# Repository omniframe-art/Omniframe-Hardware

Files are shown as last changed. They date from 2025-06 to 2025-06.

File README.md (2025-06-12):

**Omniframe Hardware**

Omniframe is an open source e-paper digital frame. This repository includes the source and fabrication files for the main and secondary boards for driving the [13.3" Monochrome e-ink display](https://www.eink.com/product/detail/VB3300-NCB).

Screenshot 2025-06-12 at 5 02 29 PM

Main Board includes:
* ESP32-S3 N8R2
* TPS65185
* AP61100
* BQ25505
* BQ24040
* MicroSD card slot
  
Screenshot 2025-06-10 at 2 24 29 PM

Secondary Board includes:
* USB Type-C Port
* Pushbutton connected to ESP GPIO

Exports include:
* Gerber files
* Assembly files
* BOM
* STEP files

The main board includes Molex 5023520-series connectors for Solar Array, Battery, and and Secondary Board. By default, connecting the main and secondary boards is done with a ribbon cable with [Molex 5023510500](https://www.digikey.com/en/products/detail/molex/5023510500/4555379) housings. Alternatively, the source files can be modified to accomodate for other connectors. 

To operate the e-paper display using this hardware, flash the [Omniframe Firmware](https://github.com/omniframe-art/Omniframe-Firmware) to the ESP. For converting and transferring images set up the [Private Image Server](https://github.com/omniframe-art/Private-Image-Server).

**Licensing**

The Omniframe framework is licensed under the terms of the [Creative Commons Attribution-ShareAlike 4.0 International License](https://creativecommons.org/licenses/by-sa/4.0/).

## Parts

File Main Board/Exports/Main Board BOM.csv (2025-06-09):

Reference | Value | Footprint | Qty | DNP | Description
C1,C46 | 2u2 | Capacitor_SMD:C_0805_2012Metric | 2 |  | Capacitor
C2,C4,C22,C31,C47,C48 | 100n | Capacitor_SMD:C_0603_1608Metric | 6
C3,C23,C32,C36,C42 | 22u | Capacitor_SMD:C_0805_2012Metric | 5
C5,C13,C26,C27,C28,C33,C34,C45,C51,C52,C53 | 4u7 | Capacitor_SMD:C_0805_2012Metric | 11
C9,C10,C11,C49 | 10n | Capacitor_SMD:C_0603_1608Metric | 4
C20,C21 | 1u | Capacitor_SMD:C_0805_2012Metric | 2
C30,C35,C43,C50,C59 | 10u | Capacitor_SMD:C_0805_2012Metric | 5
C54,C55,C58 | 1uF/25V | Capacitor_SMD:C_0805_2012Metric | 3
C56,C57 | 1uF/50V | Capacitor_SMD:C_0805_2012Metric | 2
D1,D9 | BAS3010B-03W | Diode_SMD:D_SOD-323 | 2
D7,D8 | BAV99,215 | Libraries:SOT-23TO-236_318-08_ONS-M | 2
H1,H2,H3,H4 | MountingHole | MountingHole:MountingHole_3.2mm_M3 | 4
IC1 | ESP32-S3-WROOM-1-N8R2 | ESP:ESP32S3WROOM1N8R2 | 1 |  | WiFi Modules - 802.11 (Engineering Samples Only) SMD Module, ESP32-S3R2, 2 MB PSRAM, 8 MB SPI Flash, PCB Antenna ,,
IC2 | TPS65185RSLT | TPS65185:QFN40P600X600X100-49N-D | 1 |  | Power Management Specialised - PMIC PMIC FOR E-INK PAPER DISPLAY
IC4 | AP61100 | AP61300:SOTFL50P162X60-6N | 1 |  | DCDC Conv LV Buck SOT563 T&R 3K
J2 | 5023520300 | 5023520300:CONN03_502352_MOL | 1
J3 | FH26W-39S-0.3SHW(60) | Libraries:FH26W39S03SHW60 | 1
J4 | 5023520500 | 5023520500:CONN05_502352_MOL | 1
J5 | MSD-1-A | MSD-1-A:CUI_MSD-1-A | 1
J6 | 5023520200 | 5023520200:CONN02_502352_MOL | 1
L1 | 4.7uH 2A | Inductor_SMD:L_Vishay_IFSC-1515AH_4x4x1.8mm | 1
L3 | LPS4018-223MRC | LPS4018_223MRC:IND_LPS4018-223MRC | 1
L4 | NRH3012T1R0NN | Inductor_SMD:L_Changjiang_FNR3012S | 1
L5 | 2.2uH 2A | Inductor_SMD:L_Changjiang_FNR4012S | 1 |  | Inductor
Q1,Q5 | 2N7002 | Libraries:SOT-23TO-236_318-08_ONS-M | 2 |  | N-MOSFET transistor, drain/source/gate
Q2,Q4,Q6 | BSS84-7-F | Package_TO_SOT_SMD:SOT-23-3 | 3 |  | P-MOSFET transistor, drain/source/gate
R1,R5,R8,R15,R16,R17,R18,R30,R33,R34 | 10k | Resistor_SMD:R_0402_1005Metric | 10
R10,R12,R14,R40,R41,R42,R43 | 47k | Resistor_SMD:R_0402_1005Metric | 7
R11,R19 | 30k | Resistor_SMD:R_0402_1005Metric | 2
R13 | 7M32 | Resistor_SMD:R_0402_1005Metric | 1
R20 | 5M62 | Resistor_SMD:R_0402_1005Metric | 1
R21 | 1M1 | Resistor_SMD:R_0402_1005Metric | 1
R22 | 7M68 | Resistor_SMD:R_0402_1005Metric | 1
R23 | 2k | Resistor_SMD:R_0402_1005Metric | 1
R25 | 44k2 | Resistor_SMD:R_0402_1005Metric | 1
R26 | 200k | Resistor_SMD:R_0402_1005Metric | 1
R27 | 4M22 | Resistor_SMD:R_0402_1005Metric | 1
R28 | 590 | Resistor_SMD:R_0402_1005Metric | 1
R35 | 52k3 | Resistor_SMD:R_0402_1005Metric | 1
R36,R38 | 1M | Resistor_SMD:R_0402_1005Metric | 2
R37 | 41k6 | Resistor_SMD:R_0402_1005Metric | 1
R39 | 43k | Resistor_SMD:R_0402_1005Metric | 1
R44 | 100k | Resistor_SMD:R_0402_1005Metric | 1
S1 | TS5216A 160gf 025 | TS18-5-25-SL-260-SMT-TR:TS18525SL260SMTTR | 1 |  | None Without 50mA 5.2mm 100MΩ 100000 Times 12V 160gf 5.2mm 1.6mm Round Button Standing paste SPST SMD-4P,5.2x5.2mm Tactile Switches ROHS
TH1 | 10k/3380K | Resistor_SMD:R_0402_1005Metric | 1
U1 | BQ25505 | bq25505:QFN50P350X350X100-21N-D | 1 |  | Nano Power Boost Charger and Buck Converter for Energy Harvester Powered Applications, QFN-20
U3 | BQ24040DSQR | BQ24040:SON40P200X200X80-11N | 1
Y1 | SIT1533AC-H4-DCC-32.768E | Libraries:XTAL4_SiT1533_SIT | 1

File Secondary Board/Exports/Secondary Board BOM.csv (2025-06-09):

Id | Designator | Footprint | Quantity | Designation | Supplier and ref
1 | J3 | CONN05_502352_MOL | 1 | 5023520500
2 | R2,R1 | R_0402_1005Metric | 2 | 5k1
3 | J1 | USB4145030070C | 1 | USB4145-03-0070-C
4 | S2 | TL1014BF220QG | 1 | TL1014BF220QG
5 | B1 | SOT-23-6 | 1 | USBLC6-2SC6

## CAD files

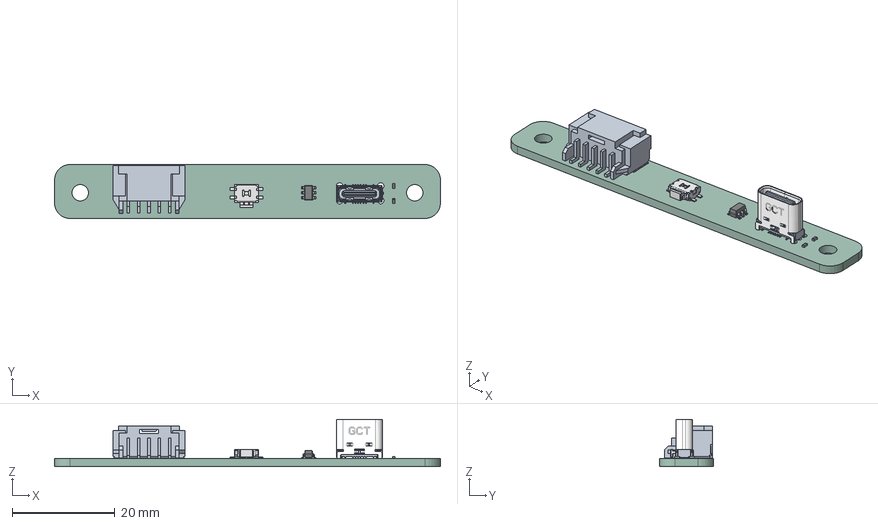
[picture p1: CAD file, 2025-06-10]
Secondary Board/Exports/Secondary Board.step
75.0 x 10.5 x 9.22 mm
R_0402_1005Metric x 2
USB4145-03-0070-C
P:\E-Switch Secure\3D_MODELS_STP_FORMAT\TL1014BFxxxQG.stp
SOT_23_6
Secondary Board_PCB

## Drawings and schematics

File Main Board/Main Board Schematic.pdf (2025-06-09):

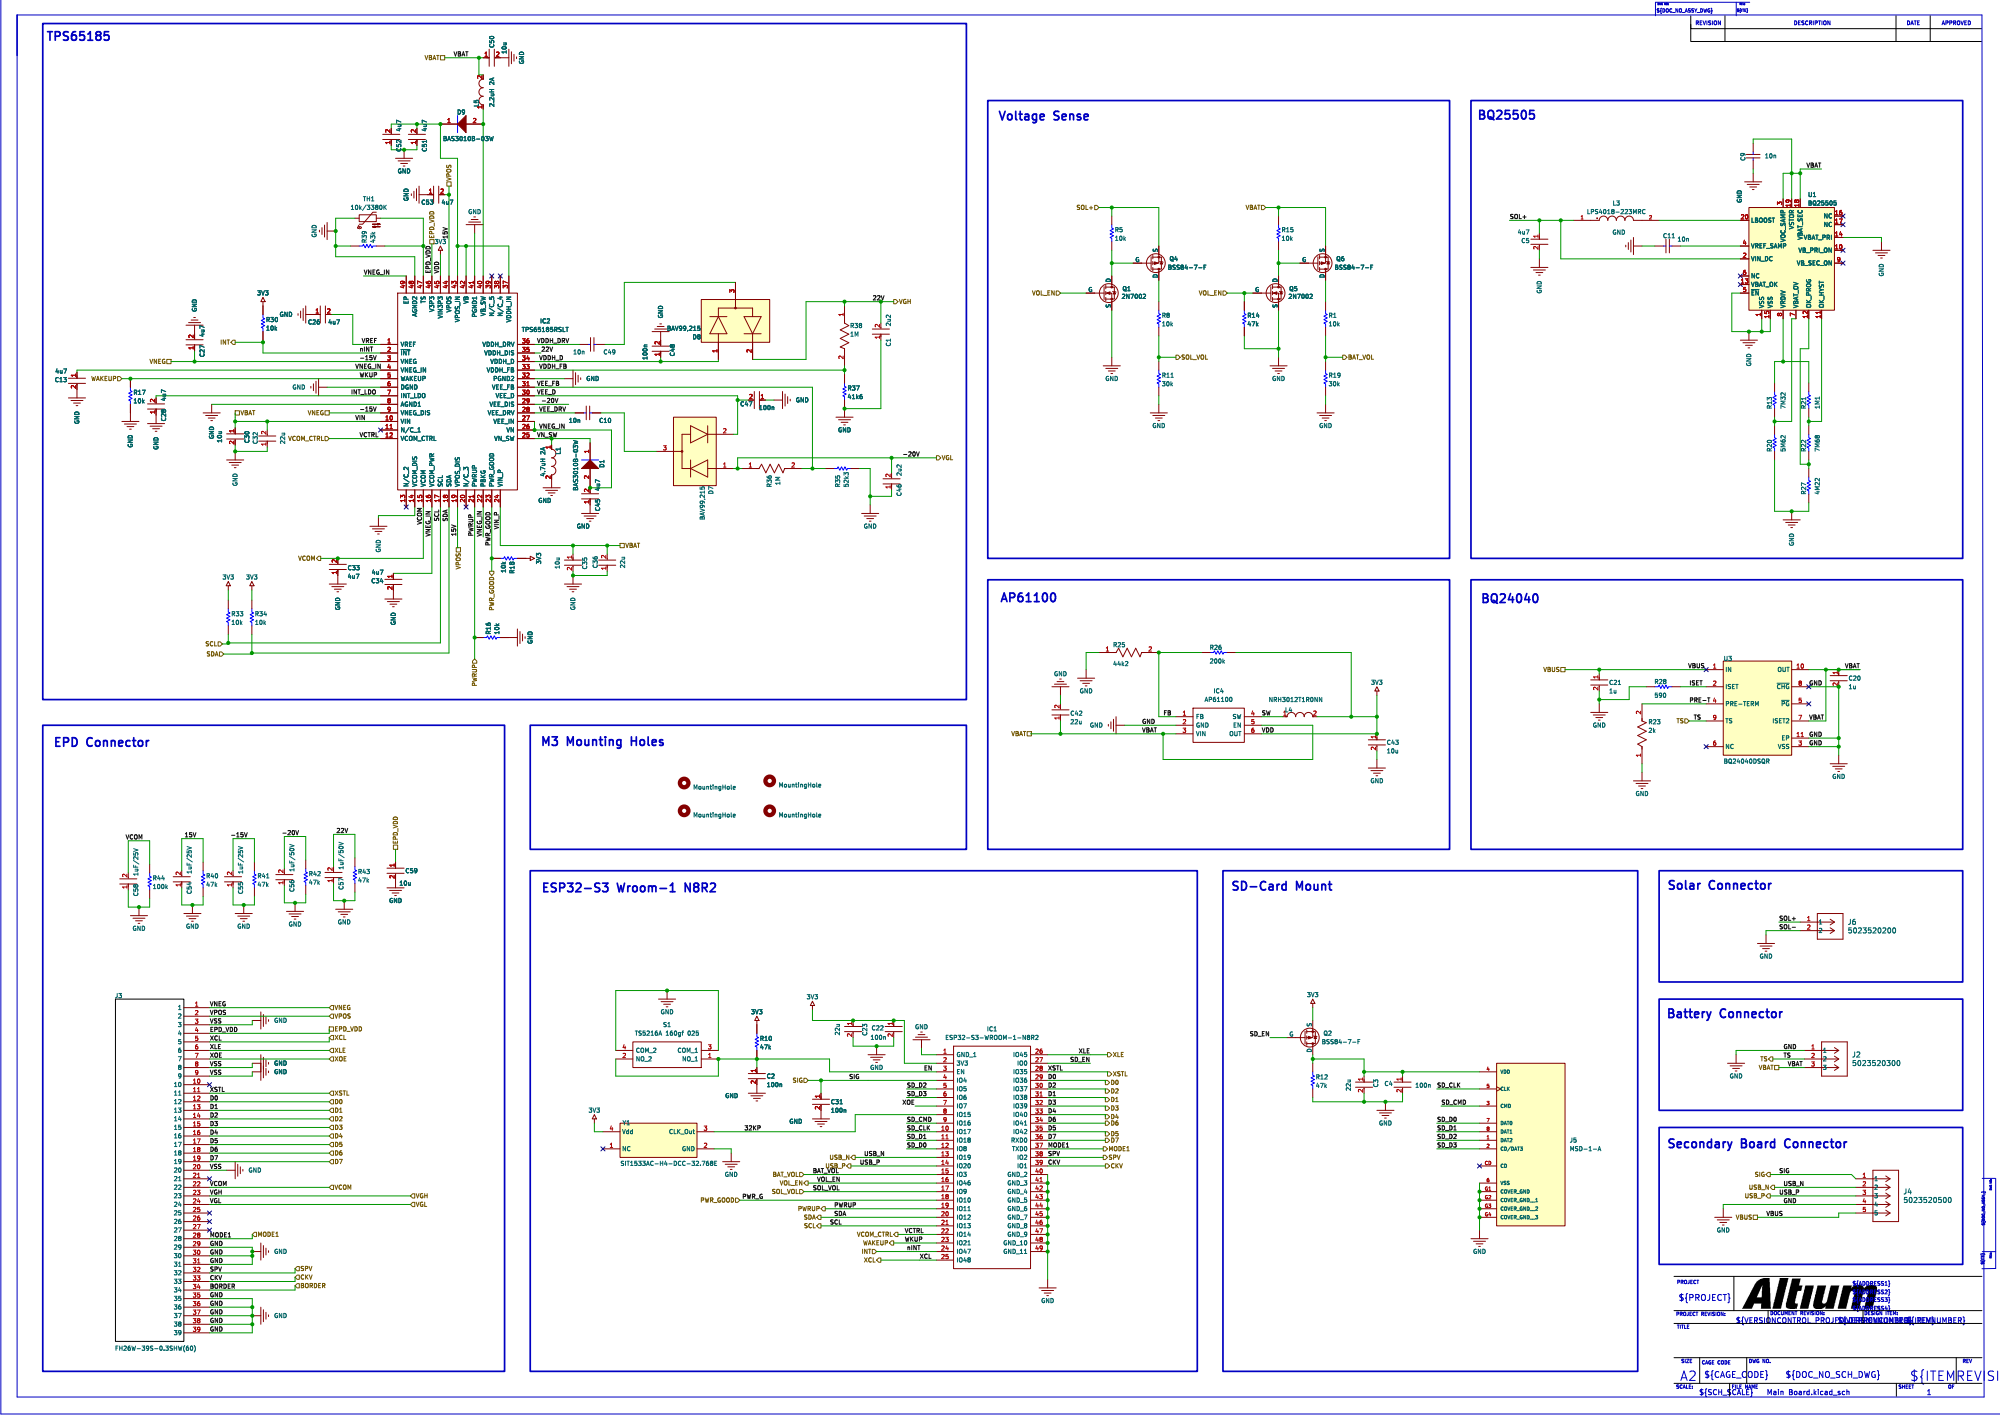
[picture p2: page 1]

1 2 C51 4u7 NC 1 GND 2 CLK_Out 3 Vdd 4 Y1 SIT1533AC-H4-DCC-32.768E NO_1 1 NO_2 2 COM_1 3 COM_2 4 S1 TS5216A 160gf 025 GND

DWG NO.DOCUMENT REVISION:

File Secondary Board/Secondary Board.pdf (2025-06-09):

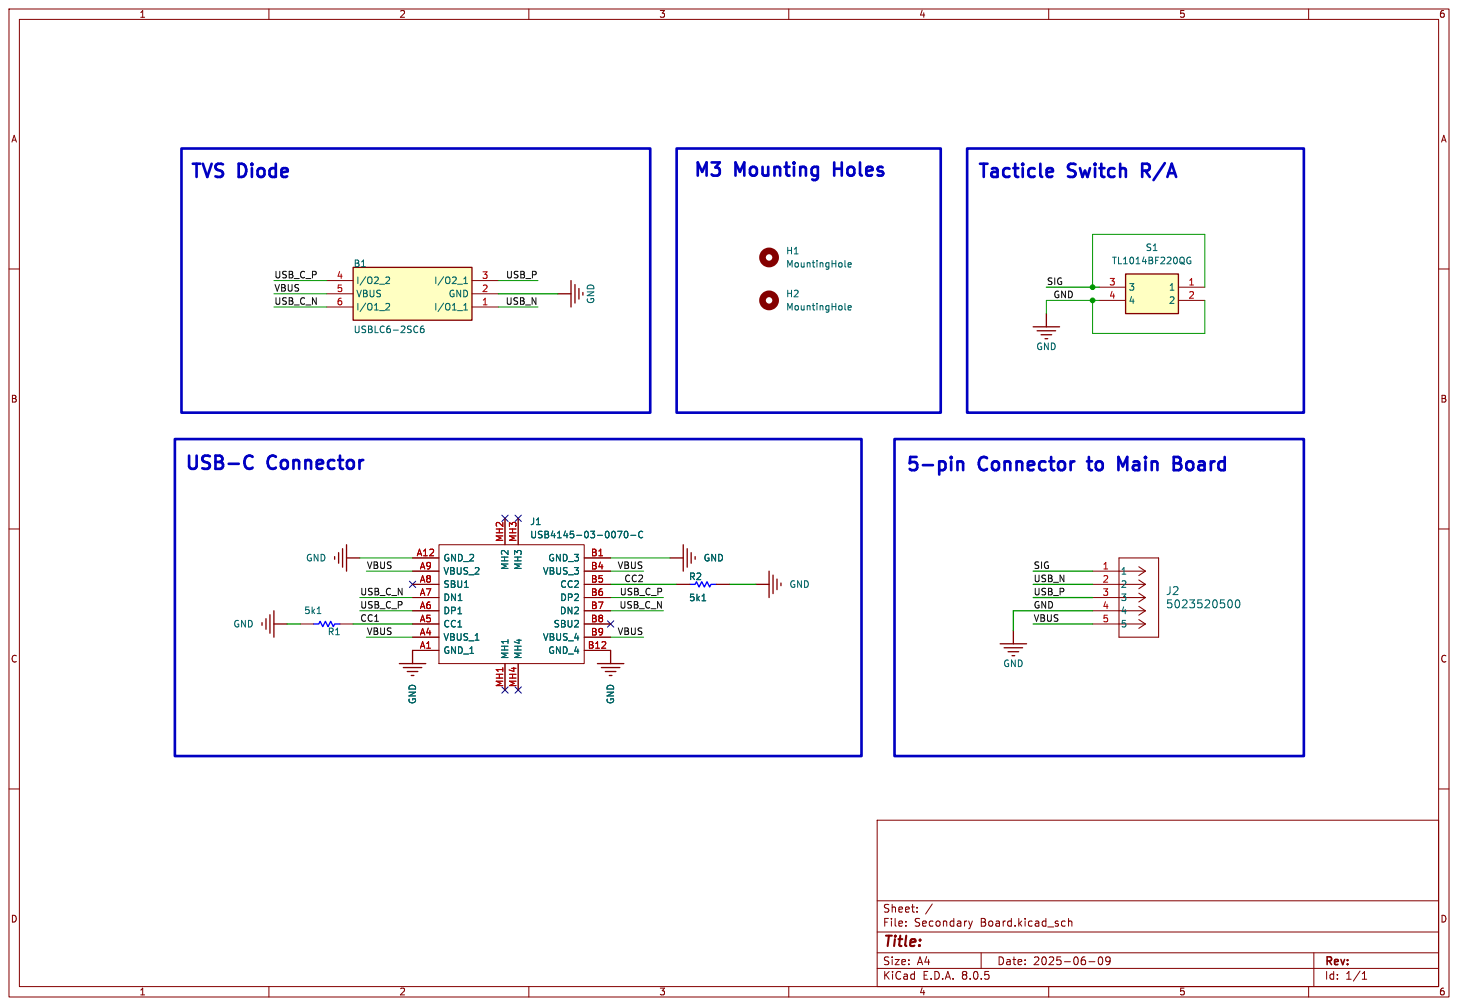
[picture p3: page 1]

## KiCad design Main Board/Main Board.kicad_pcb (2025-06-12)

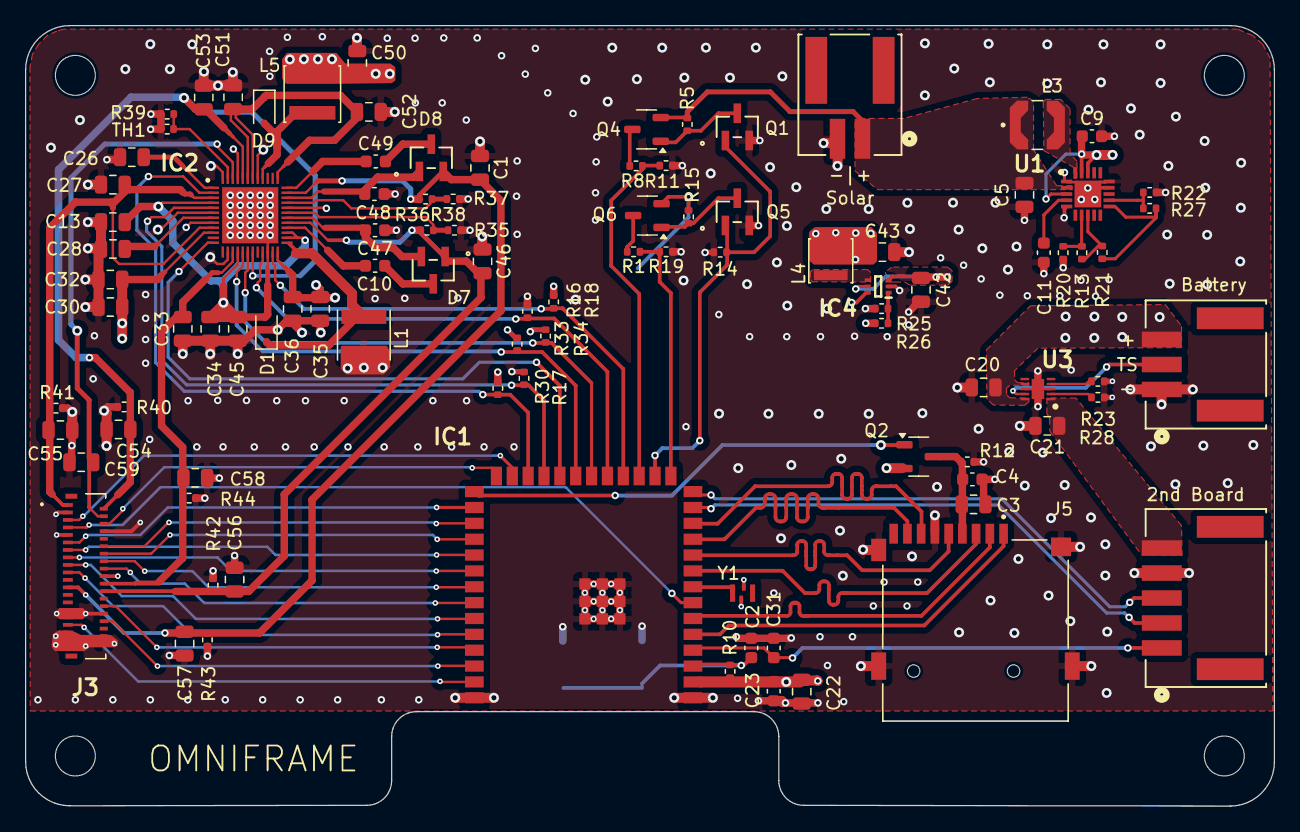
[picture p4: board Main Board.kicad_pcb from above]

Board: 4 copper layers, 100.0 x 62.5 mm, 104 parts (1 on the bottom side), 79 nets.

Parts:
C1, C46: 2u2; C_0805_2012Metric
C2, C4, C22, C31, C47, C48: 100n; C_0603_1608Metric
C3, C23, C32, C36, C42: 22u; C_0805_2012Metric
C5, C13, C26, C27, C28, C33, C34, C45, C51, C52, C53: 4u7; C_0805_2012Metric
C9, C10, C11, C49: 10n; C_0603_1608Metric
C20, C21: 1u; C_0805_2012Metric
C30, C35, C43, C50, C59: 10u; C_0805_2012Metric
C54, C55, C58: 1uF/25V; C_0805_2012Metric
C56, C57: 1uF/50V; C_0805_2012Metric
D1, D9: BAS3010B-03W; D_SOD-323
D7, D8: BAV99,215; SOT-23TO-236_318-08_ONS-M
H1, H2, H3, H4: MountingHole; MountingHole_3.2mm_M3
IC1: ESP32-S3-WROOM-1-N8R2; ESP32S3WROOM1N8R2
IC2: TPS65185RSLT; QFN40P600X600X100-49N-D
IC4: AP61100; SOTFL50P162X60-6N
J2: 5023520300; CONN03_502352_MOL
J3: FH26W-39S-0.3SHW(60); FH26W39S03SHW60
J4: 5023520500; CONN05_502352_MOL
J5: MSD-1-A; CUI_MSD-1-A
J6: 5023520200; CONN02_502352_MOL
L1: 4.7uH 2A; L_Vishay_IFSC-1515AH_4x4x1.8mm
L3: LPS4018-223MRC; IND_LPS4018-223MRC
L4: NRH3012T1R0NN; L_Changjiang_FNR3012S
L5: 2.2uH 2A; L_Changjiang_FNR4012S
Q1, Q5: 2N7002; SOT-23TO-236_318-08_ONS-M
Q2, Q4, Q6: BSS84-7-F; SOT-23-3
R1, R5, R8, R15, R16, R17, R18, R30, R33, R34: 10k; R_0402_1005Metric
R10, R12, R14, R40, R41, R42, R43: 47k; R_0402_1005Metric
R11, R19: 30k; R_0402_1005Metric
R13: 7M32; R_0402_1005Metric
R20: 5M62; R_0402_1005Metric
R21: 1M1; R_0402_1005Metric
R22: 7M68; R_0402_1005Metric
R23: 2k; R_0402_1005Metric
R25: 44k2; R_0402_1005Metric
R26: 200k; R_0402_1005Metric
R27: 4M22; R_0402_1005Metric
R28: 590; R_0402_1005Metric
R35: 52k3; R_0402_1005Metric
R36, R38: 1M; R_0402_1005Metric
R37: 41k6; R_0402_1005Metric
R39: 43k; R_0402_1005Metric
R44: 100k; R_0402_1005Metric
S1: TS5216A 160gf 025; TS18525SL260SMTTR
TH1: 10k/3380K; R_0402_1005Metric
U1: BQ25505; QFN50P350X350X100-21N-D
U3: BQ24040DSQR; SON40P200X200X80-11N
Y1: SIT1533AC-H4-DCC-32.768E; XTAL4_SiT1533_SIT

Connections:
3V3: C22.1, C23.1, C43.1, IC1.2 (3V3), IC2.45 (VIN3P3), IC4.6 (OUT), L4.2, Q2.2 (S), R10.2, R18.2, R26.2, R30.2, R33.2, R34.2, Y1.4 (Vdd)
/15V: C53.2, C54.2, IC2.19 (VPOS_DIS), IC2.44 (VPOS), J3.2, R40.2
/22V: C1.2, C57.2, D8.2, IC2.35 (VDDH_DIS), J3.23, R38.1, R43.2
/32KP: IC1.8 (IO15), Y1.3 (CLK_Out)
/-15V: C27.1, C55.2, IC2.3 (VNEG), IC2.9 (VNEG_DIS), J3.1, R41.2
/-20V: C46.2, C56.2, D7.1, IC2.29 (VEE_DIS), J3.24, R36.1, R42.2
/BAT_VOL: IC1.15 (IO3), R1.1, R19.2
/CKV: IC1.39 (IO1), J3.33
/D0: IC1.29 (IO36), J3.12
/D1: IC1.31 (IO38), J3.13
/D2: IC1.30 (IO37), J3.14
/D3: IC1.32 (IO39), J3.15
/D4: IC1.33 (IO40), J3.16
/D5: IC1.35 (IO42), J3.17
/D6: IC1.34 (IO41), J3.18
/D7: IC1.36 (RXD0), J3.19
/EN: C2.1, IC1.3 (EN), R10.1, S1.1 (NO_1), S1.2 (NO_2)
/EPD_VDD: C59.1, IC2.46 (V3P3), J3.4
/FB: IC4.1 (FB), R25.2, R26.1
/INT_LDO: C28.2, IC2.7 (INT_LDO)
/ISET: R28.2, U3.2 (ISET)
/MODE1: IC1.37 (TXD0), J3.28
/PRE-T: R23.2, U3.4 (PRE-TERM)
/PWRUP: IC1.19 (IO11), IC2.21 (PWRUP), R16.2
/PWR_G: IC1.18 (IO10), IC2.23 (PWR_GOOD), R18.1
/SCL: IC1.21 (IO13), IC2.17 (SCL), R33.1
/SDA: IC1.20 (IO12), IC2.18 (SDA), R34.1
/SD_CLK: IC1.10 (IO17), J5.5 (CLK)
/SD_CMD: IC1.9 (IO16), J5.3 (CMD)
/SD_D0: IC1.12 (IO8), J5.7 (DAT0)
/SD_D1: IC1.11 (IO18), J5.8 (DAT1)
/SD_D2: IC1.5 (IO5), J5.1 (DAT2)
/SD_D3: IC1.6 (IO6), J5.2 (CD/DAT3)
/SD_EN: IC1.27 (IO0), Q2.1 (G)
/SIG: C31.1, IC1.4 (IO4), J4.1
/SOL+: C5.1, J6.1, L3.1, Q4.2 (S), R5.2, U1.2 (VIN_DC)
/SOL_VOL: IC1.17 (IO9), R8.1, R11.2
/SPV: IC1.38 (IO2), J3.32
/SW: IC4.4 (SW), L4.1
/TS: J2.2, U3.9 (TS)
/USB_N: IC1.13 (IO19), J4.2
/USB_P: IC1.14 (IO20), J4.3
/VBAT: C9.1, C20.1, C30.1, C32.2, C35.1, C36.2, C42.1, C50.1, IC2.10 (VIN), IC2.24 (VIN_P), IC4.3 (VIN), IC4.5 (EN), J2.3, L5.2, Q6.2 (S), R15.2, U1.3 (VOC_SAMP), U1.18 (VBAT_SEC), U1.19 (VSTOR), U3.7 (ISET2), U3.10 (OUT)
/VBUS: C21.1, J4.5, U3.1 (IN)
/VCOM: C33.2, C58.2, IC2.15 (VCOM), J3.22, R44.2
/VCTRL: IC1.22 (IO14), IC2.12 (VCOM_CTRL)
/VDDH_D: C48.1, D8.1, IC2.34 (VDDH_D)
/VDDH_DRV: C49.1, IC2.36 (VDDH_DRV)
/VDDH_FB: IC2.33 (VDDH_FB), R37.2, R38.2
/VEE_D: C47.2, D7.2, IC2.30 (VEE_D)
/VEE_DRV: C10.1, IC2.28 (VEE_DRV)
/VEE_FB: IC2.31 (VEE_FB), R35.2, R36.2
/VNEG_IN: C13.1, C34.1, C45.2, D1.2 (A), IC2.4 (VNEG_IN), IC2.16 (VCOM_PWR), IC2.22 (PBKG), IC2.26 (VN), IC2.27 (VEE_IN), IC2.49 (EP)
/VN_SW: D1.1 (K), IC2.25 (VN_SW), L1.1
/VOL_EN: IC1.16 (IO46), Q1.1 (G), Q5.1 (G), R14.2
/VREF: C26.2, IC2.1 (VREF)
/WKUP: IC1.23 (IO21), IC2.5 (WAKEUP), R17.2
/XCL: IC1.25 (IO48), J3.5
/XLE: IC1.26 (IO45), J3.6
/XOE: IC1.7 (IO7), J3.7
/XSTL: IC1.28 (IO35), J3.11
/nINT: IC1.24 (IO47), IC2.2 (~INT), R30.1
GND: C1.1, C2.2, C3.2, C4.2, C5.2, C9.2, C11.2, C13.2, C20.2, C21.2, C22.2, C23.2, C26.1, C27.2, C28.1, C30.2, C31.2, C32.1, C33.1, C34.2, C35.2, C36.1, C42.2, C43.2, C45.1, C46.1, C47.1, C48.2, C50.2, C51.1, C52.1, C53.1, C54.1, C55.1, C56.1, C57.1, C58.1, C59.2, IC1.1 (GND_1), IC1.40 (GND_2), IC1.41 (GND_3), IC1.42 (GND_4), IC1.43 (GND_5), IC1.44 (GND_6), IC1.45 (GND_7), IC1.46 (GND_8), IC1.47 (GND_9), IC1.48 (GND_10), IC1.49 (GND_11), IC2.6 (DGND), IC2.8 (AGND1), IC2.14 (VCOM_DIS), IC2.32 (PGND2), IC2.41 (PGND1), IC2.48 (AGND2), IC4.2 (GND), J2.1, J3.3, J3.8, J3.9, J3.20, J3.29, J3.30, J3.31, J3.35, J3.36, J3.37, J3.38, J3.39, J4.4, J5.6 (VSS), J5.G1 (COVER_GND), J5.G2 (COVER_GND__1), J5.G3 (COVER_GND__2), J5.G4 (COVER_GND__3), J6.2, L1.2, Q1.2 (S), Q5.2 (S), R11.1, R12.1, R14.1, R16.1, R17.1, R19.1, R20.1, R23.1, R25.1, R27.1, R28.1, R35.1, R37.1, R39.2, R40.1, R41.1, R42.1, R43.1, R44.1, S1.3 (COM_1), S1.4 (COM_2), TH1.1, U1.1 (VSS), U1.5 (~EN), U1.14 (VBAT_PRI), U1.15 (VSS), U3.3 (VSS), U3.8 (~CHG), U3.11 (EP), Y1.2 (GND)
unnamed: C10.2, D7.3
unnamed: C49.2, D8.3
unnamed: D9.2 (A), IC2.40 (VB_SW), L5.1
unnamed: C51.2, C52.2, D9.1 (K), IC2.37 (VDDH_IN), IC2.42 (VB), IC2.43 (VPOS_IN)
unnamed: IC2.47 (TS), R39.1, TH1.2
unnamed: C3.1, C4.1, J5.4 (VDD), Q2.3 (D), R12.2
unnamed: Q1.3 (D), Q4.1 (G), R5.1
unnamed: Q4.3 (D), R8.2
unnamed: Q5.3 (D), Q6.1 (G), R15.1
unnamed: Q6.3 (D), R1.2
unnamed: L3.2, U1.20 (LBOOST)
unnamed: R21.1, R22.2, U1.11 (OK_HYST)
unnamed: R22.1, R27.2, U1.12 (OK_PROG)
unnamed: R13.1, R20.2, U1.7 (VBAT_OV)
unnamed: R13.2, R21.2, U1.8 (VRDIV)
unnamed: C11.1, U1.4 (VREF_SAMP)

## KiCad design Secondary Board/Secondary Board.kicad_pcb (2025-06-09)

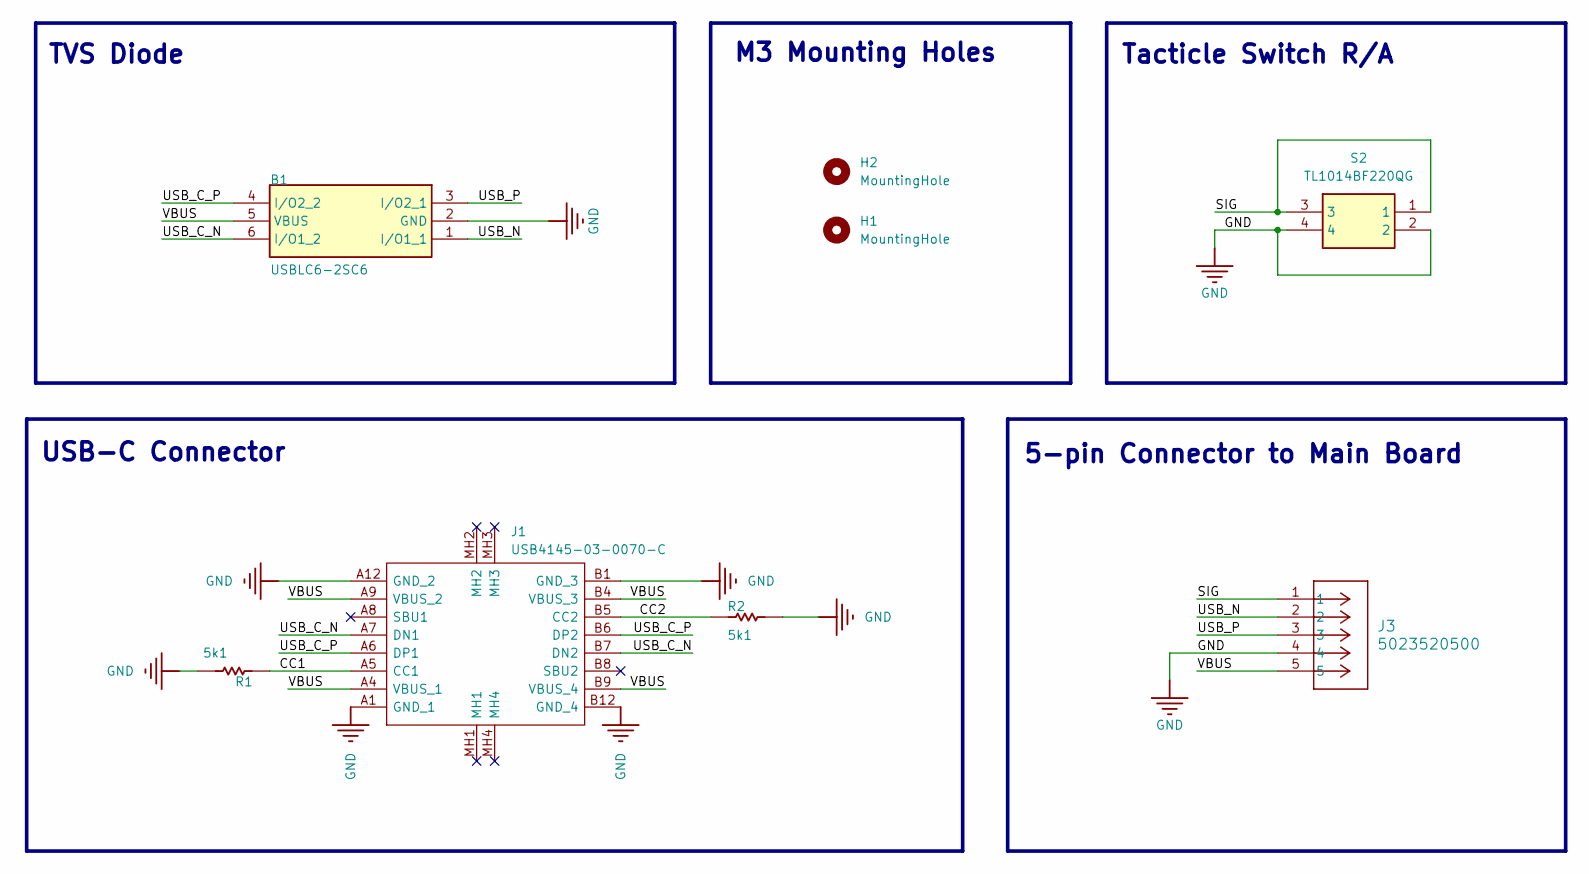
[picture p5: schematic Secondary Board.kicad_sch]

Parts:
B1: USBLC6-2SC6; SOT-23-6; MOUSER PART NUMBER 511-USBLC6-2SC6
H1, H2: MountingHole; MountingHole_3.2mm_M3
J1: USB4145-03-0070-C; USB4145030070C; Mouser Part Number 640-USB4145-3-0070-C
J3: 5023520500; CONN05_502352_MOL
R1, R2: 5k1; R_0402_1005Metric; PART NUMBER RC0402FR-075K1L
S2: TL1014BF220QG; Mouser Part Number 612-TL1014BF220QG

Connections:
/CC1: J1.A5 (CC1), R1.1
/CC2: J1.B5 (CC2), R2.1
/SIG: J3.1, S2.1, S2.3
/USB_C_N: B1.6 (I/O1_2), J1.A7 (DN1), J1.B7 (DN2)
/USB_C_P: B1.4 (I/O2_2), J1.A6 (DP1), J1.B6 (DP2)
/USB_N: B1.1 (I/O1_1), J3.2
/USB_P: B1.3 (I/O2_1), J3.3
/VBUS: B1.5 (VBUS), J1.A4 (VBUS_1), J1.A9 (VBUS_2), J1.B4 (VBUS_3), J1.B9 (VBUS_4), J3.5
GND: B1.2 (GND), J1.A1 (GND_1), J1.A12 (GND_2), J1.B1 (GND_3), J1.B12 (GND_4), J3.4, R1.2, R2.2, S2.2, S2.4

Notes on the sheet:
Tacticle Switch R/A
5-pin Connector to Main Board
USB-C Connector
TVS Diode
M3 Mounting Holes

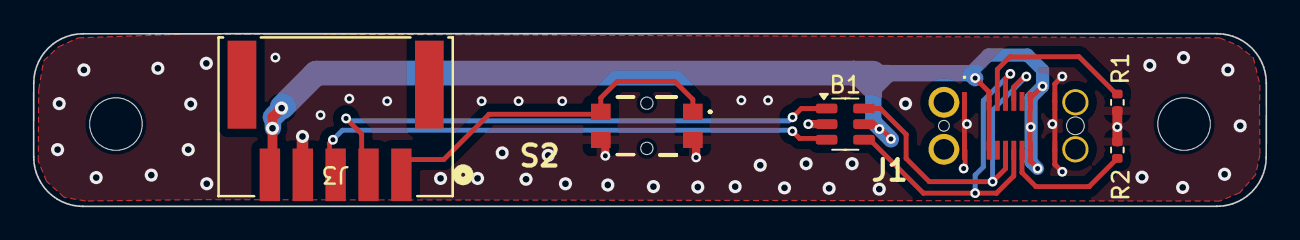
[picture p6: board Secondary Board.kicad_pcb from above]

Board: 2 copper layers, 75.0 x 10.5 mm, 8 parts (0 on the bottom side), 9 nets.

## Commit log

2025-06-10 Updated 3D-file
    [Secondary Board.step]
2025-06-12 fix silkscreen
    [Main Board-B_Cu.gbl, Main Board-B_Mask.gbs, Main Board-B_Paste.gbp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]
